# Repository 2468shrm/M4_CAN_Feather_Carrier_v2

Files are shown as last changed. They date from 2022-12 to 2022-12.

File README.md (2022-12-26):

# M4_CAN_Feather_Carrier_v2

## Board Layout
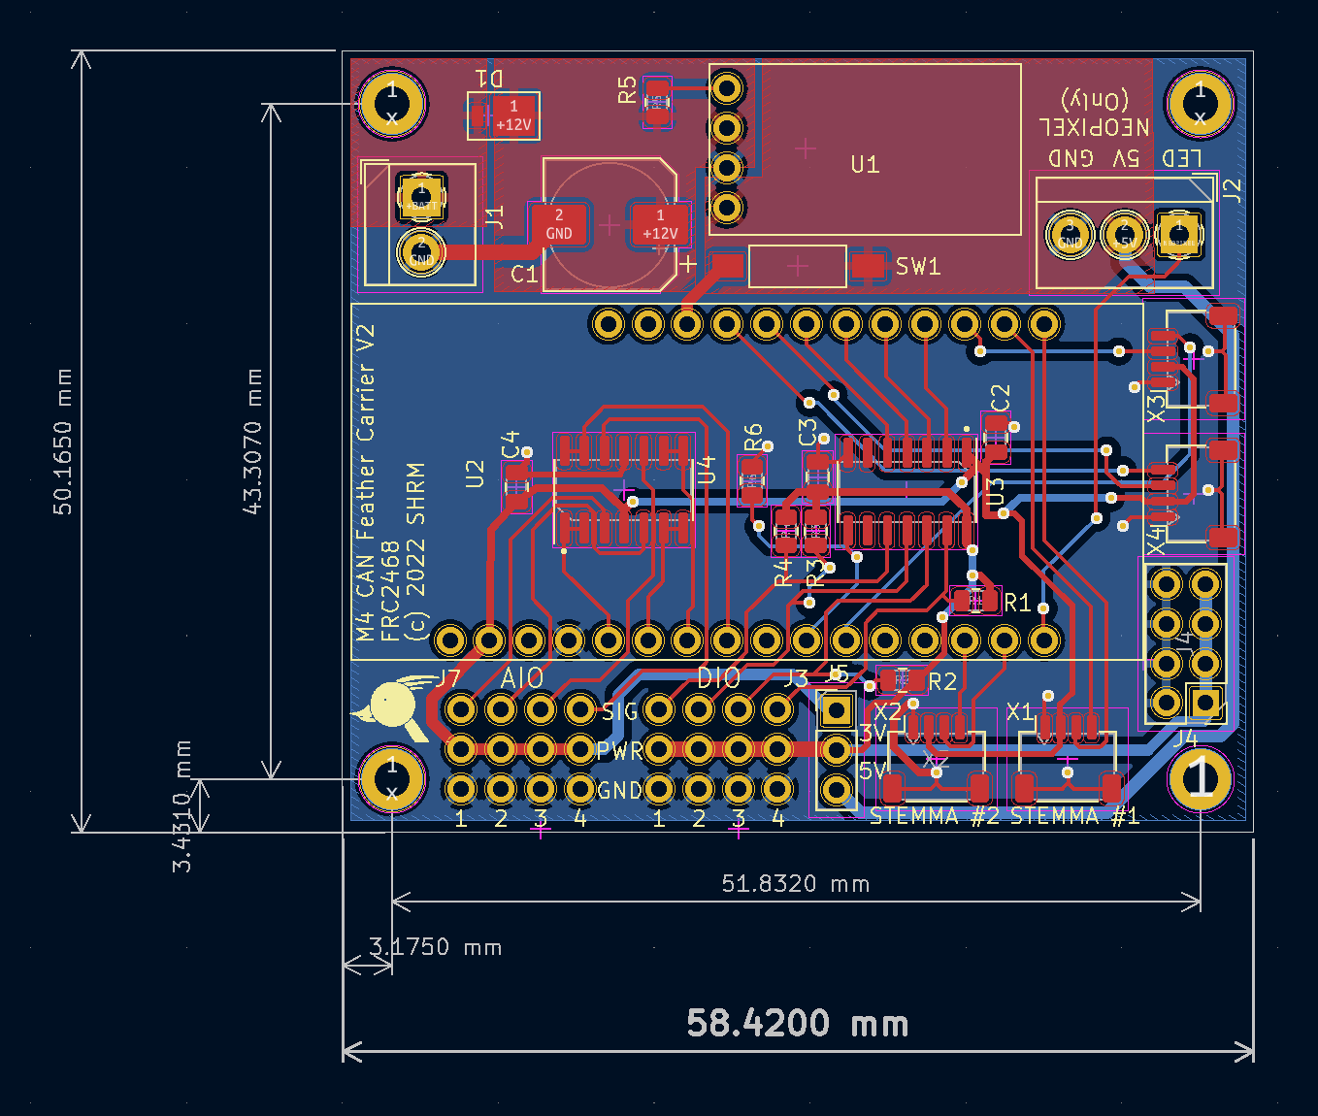
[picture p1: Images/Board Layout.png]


## Disclaimer
While I've tested a prior version of this board, this board is to be considered
alpha and subject to bugs and errors. Use at your own risk. However the Gerbers
are provided should you want to fabricate your own.

## Introduction
The carrier board is an adaptor to make using the Adafruit M4 CAN Express
Feather board more useful in FRC applications. This board was designed by mentors
of FRC2468/2687/2689. An initial version was done early in 2022, fabricated at JLCPCB
and tested to a limited degree. During the testing some weaknesses were identified and
initial design decisions questioned. Hence V2. Neither has received any actual FRC
use (it was not used by any of our teams during the 2022 competition season). However
a small number of these boards will be fabricated after the kickoff to the 2023 season.

This is the board as referenced in the [frc_can](https://github.com/2468shrm/frc_can)
project's CANCarrierBoard module (in
[can_carrier_board.py](https://github.com/2468shrm/frc_can/blob/main/can_carrier_board.py)).

## Board Description
The carrier board provides the following:
- Power interface (J1)
  - Power comes from a 12V supply through the provided 2-input screw terminal
  - The power supply contains a diode capacitor circuit to reduce the effects of FRC robot brownouts
- CAN interface
  - On the feather board
  - Note the feather board comes with termination included and active, so you must cut the termination trace jumper
- Analog I/O (AIO)
  - 4 analog inputs
  - Buffered with a unity gain opamp
  - Proded by 3-pin interface (similar to AIO on RoboRIO)
    - Pin 1: input analog signal
    - Pin 2: 3.3V supply
    - Pin 3: Ground
  - 3.3V input, max
- Digital I/O (DIO)
  - 4 digital inputs
  - Buffered with a level shifter
  - Selectable sensor voltage (VDD): 3.3V or 5V (all inputs share)
    - VDD selected by a jumper (J5)
    - 1-2 selects 3.3V
    - 2-3 selects 5V
  - Proded by 3-pin interface (similar to AIO on RoboRIO)
    - Pin 1: input analog signal
    - Pin 2: VDD supply
    - Pin 3: Ground
- Additional sensor power (J4)
	- A 2x4 header provided to provide additional VDD power to sensors
    - Intended for Adafruit beam break emitters or other multi-part sensors using an emitter and receiver pair where the receiver connects to DIO and emitter connects to the additional sensor power
- STEMMA QT/QWIIC (X1, X2, X3, X4)
  - 4 interfaces provided
- Neopixel (J2)
  - A Neopixel interface provided via a 3-input screw terminal
  - Intended to allow sensor to provide state of the sensor both over CAN and visually (i.e. sensor could be disconnected while still being useful)

## Power Interface
The initial version of this board was designed at the height of the pandemic's supply
chain shortage and so while I wanted to provide a 3A 5V supply (from 12V source) finding
the components was problematic at best. So I found a cheap, simple power supply module I
could acquire on Amazon. So I used it.

## DIO Level Shifter
The DIO interface has a level shifter between pins and MCU. The level shifter
A-side is 3.3V signaling due to the feather board's MCU requirements. The A-side
is expected to use internal pull ups if necessary. The B-side is VDD signaling
and is selected by the J5 jumper. The B-side pull ups are powered from the VDD
supply too.

The level shifter IC enable is driven by an MCU digital I/O and defaults to
off through a pull down resistor. Software must drive the OE signal high.

## Analog Buffer
A quad rail-to-rail opamp is used in unity-gain/follower configuration to buffer the
input signals to the MCU's ADCs. This is done so that sensors with large output
impedance may be connected to the ADC without significant loss in accuracy. Having
designed MCUs in the past, I'm quite aware of the effects on accuracy when using
potentiometers of 5K ohm. Most ADCs in MCUs have internal resistance and capacitacnce
that requires a low (80 ohm) source impedance to maintain spec'd accuracy.

## Updating the Programming
A switch (SW1, beside the power module) is provided to isolate the 5V generated by the
Weewooday module (U1) and the boost regulator on the Feather board. When programming a USB-C
cable is connected and the 5V is supplied on the feather board from this path. This would
lead to a contended supply. So, before programming change SW1 to open and plug in the board
to a host. Disconnect and change SW1 to closed to return to robot-supplied power.

# 3D Views of the Board
## Top
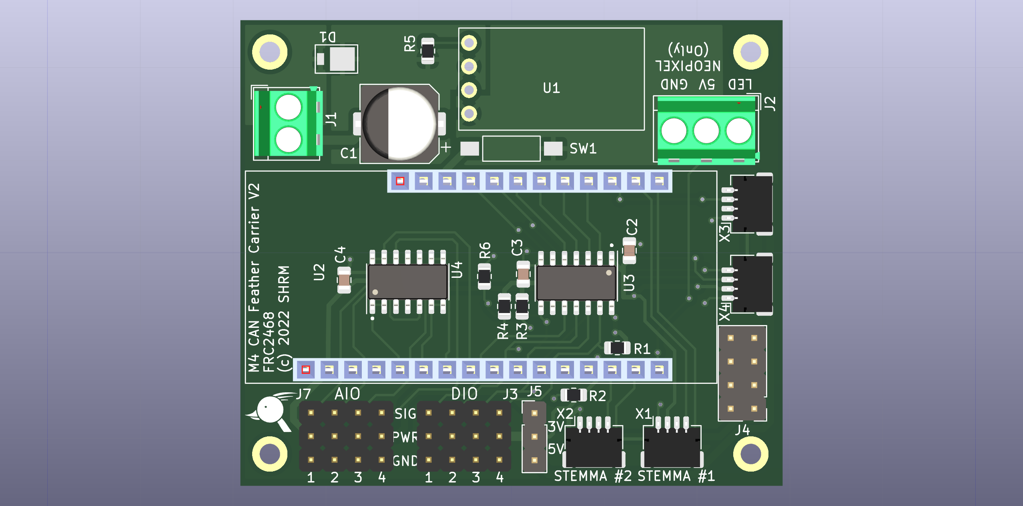
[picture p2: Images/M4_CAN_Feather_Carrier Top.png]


## Iso Front
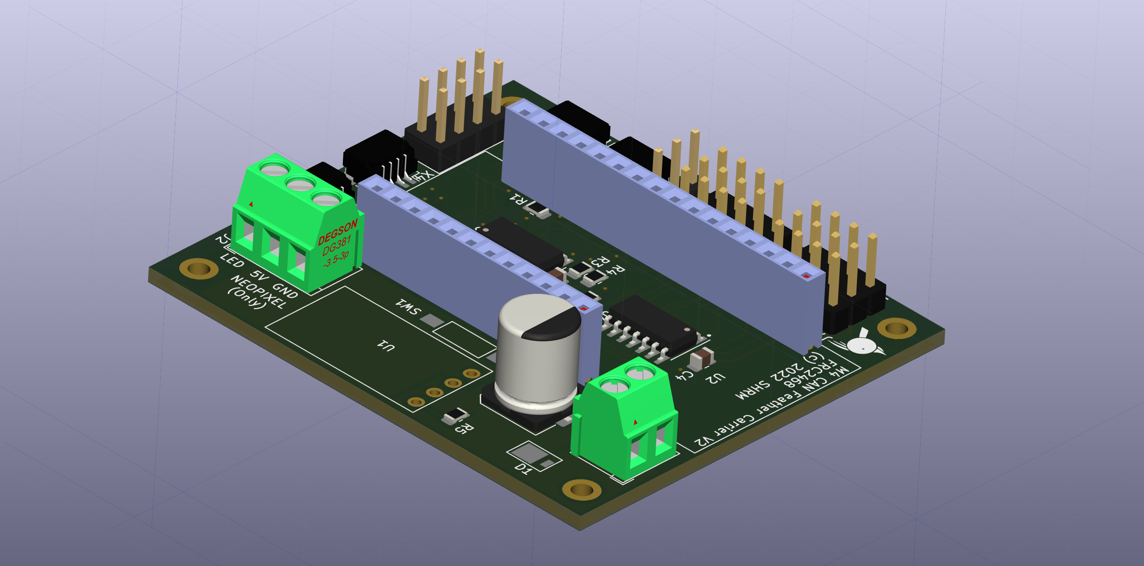
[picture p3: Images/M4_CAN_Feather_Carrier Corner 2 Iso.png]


## Iso Back
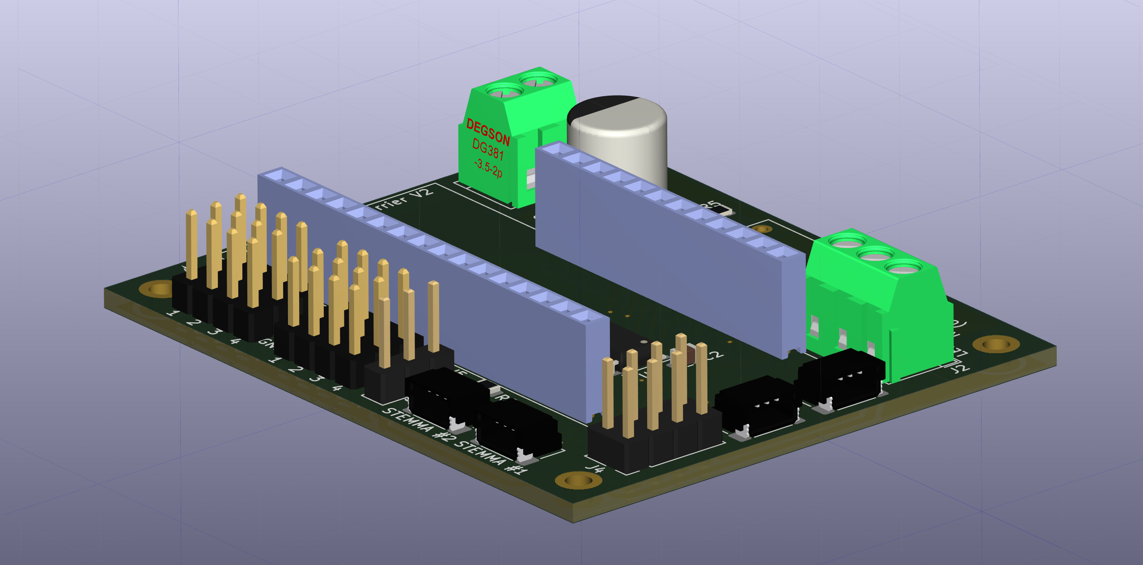
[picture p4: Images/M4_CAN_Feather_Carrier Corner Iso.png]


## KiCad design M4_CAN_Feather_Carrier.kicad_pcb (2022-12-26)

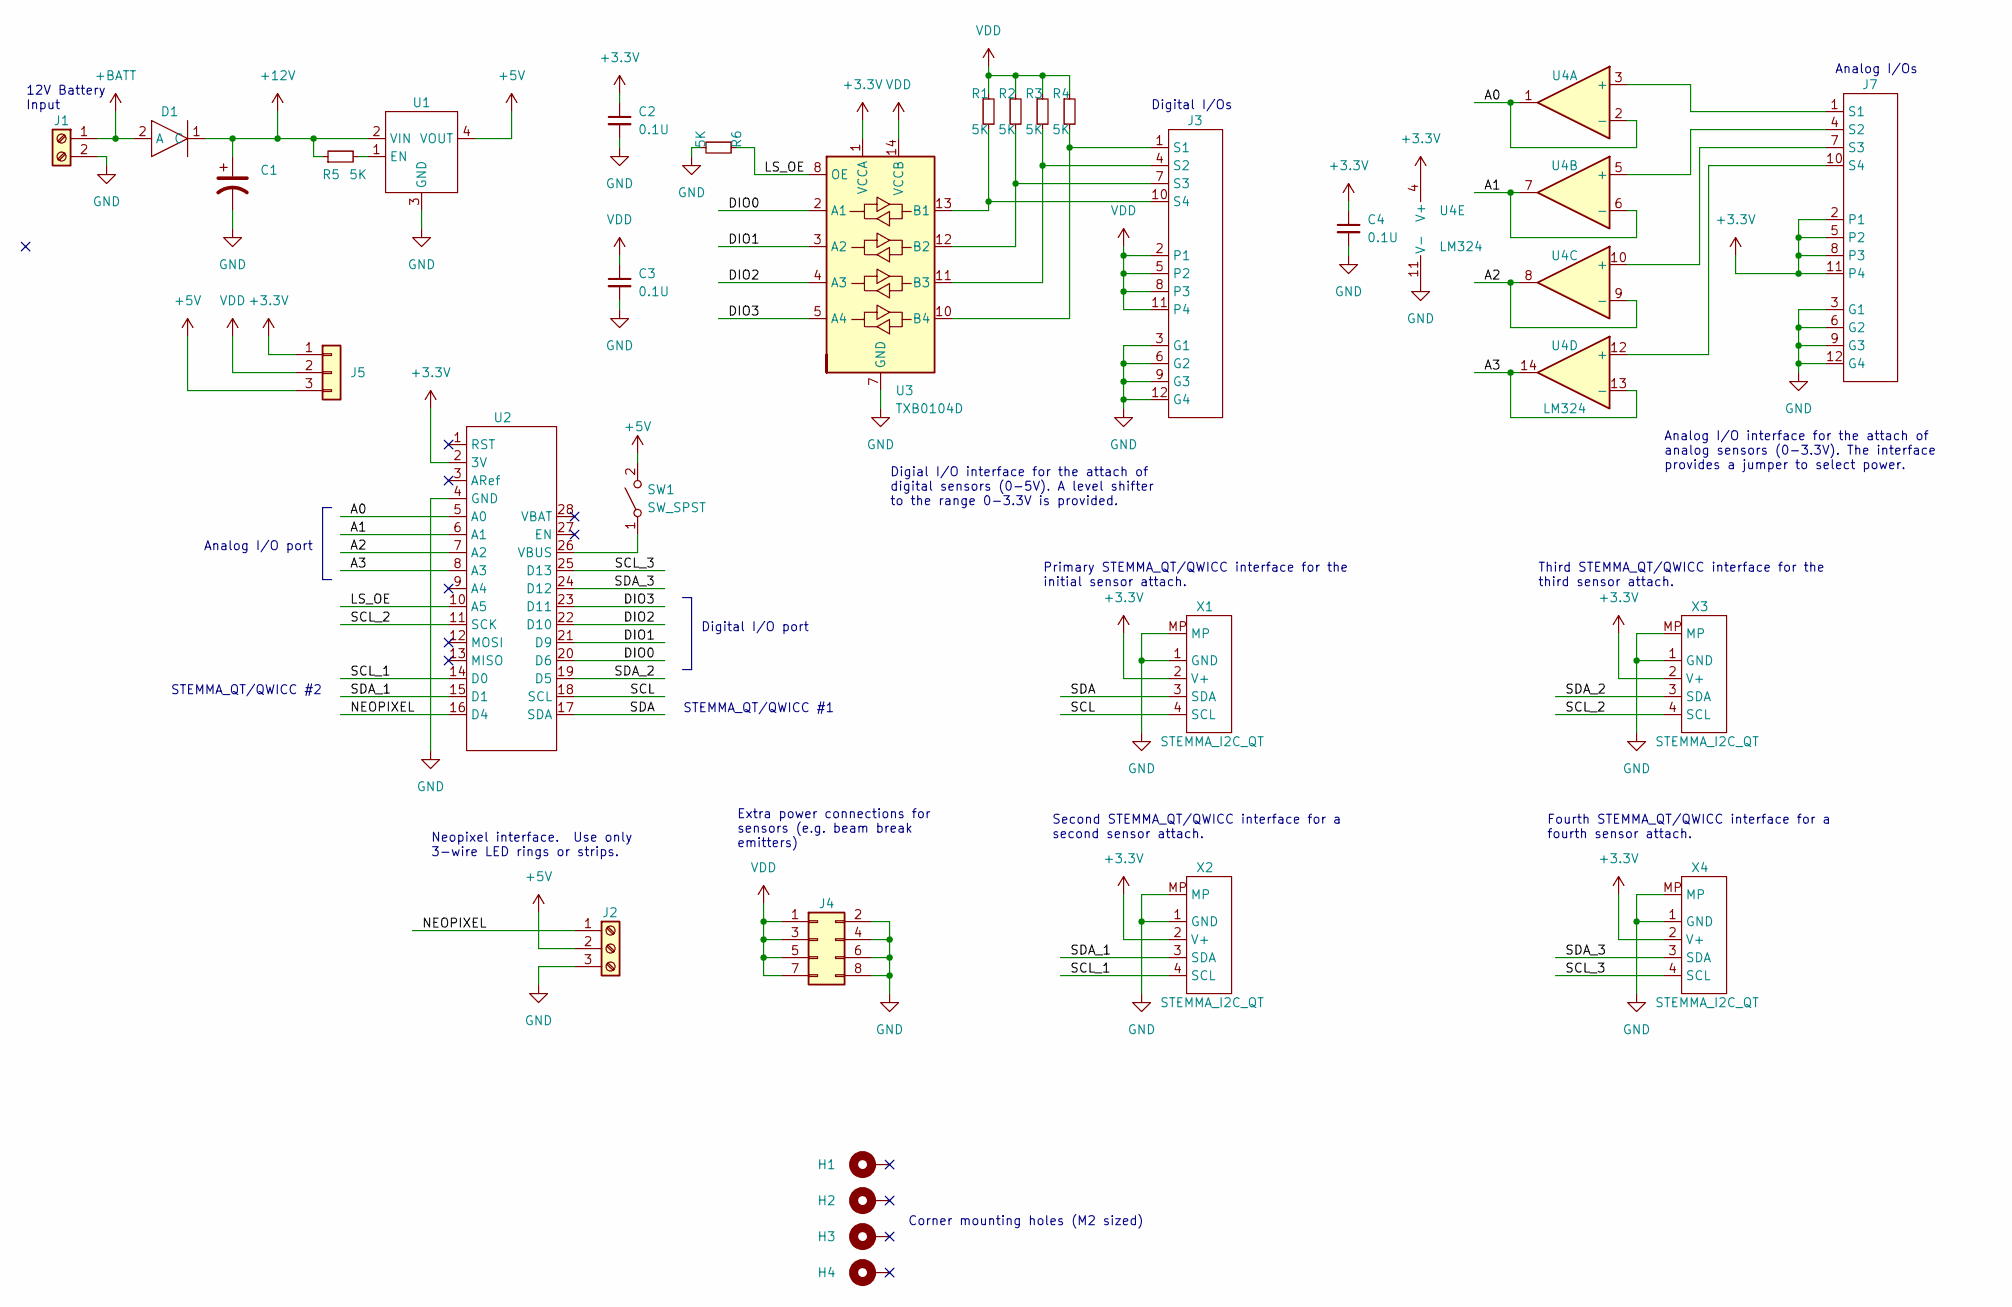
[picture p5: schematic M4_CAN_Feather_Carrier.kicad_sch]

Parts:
C1: 10u; CP_Elec_8x10
C2, C3, C4: 0.1U; C_0805_2012Metric
D1: UPR20e3; DO-216
H1, H2, H3, H4: MountingHole_Pad; MountingHole_2.2mm_M2_DIN965_Pad
J1: Screw_Terminal_01x02; TerminalBlock_4Ucon_1x02_P3.50mm_Horizontal
J2: Screw_Terminal_01x03; TerminalBlock_4Ucon_1x03_P3.50mm_Horizontal
J3, J7: conn_04_03; conn_04x03
J4: Conn_02x04_Odd_Even; PinHeader_2x04_P2.54mm_Vertical
J5: Conn_01x03; PinHeader_1x03_P2.54mm_Vertical
R1, R2, R3, R4, R5, R6: 5K; R_0805_2012Metric
SW1: SW_SPST; SPST-KJ01
U1: Weewooday-820
U2: Feather_M4_CAN_Express
U3: TXB0104D; SOIC-14_3.9x8.7mm_P1.27mm
U4: LM324; SOIC-14_3.9x8.7mm_P1.27mm
X1, X2, X3, X4: STEMMA_I2C_QT; JST_SH_SM04B-SRSS-TB_1x04-1MP_P1.00mm_Horizontal

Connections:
+3.3V: C2.1, C4.1, J5.1, J7.2 (P1), J7.5 (P2), J7.8 (P3), J7.11 (P4), U2.2 (3V), U3.1 (VCCA), U4.4 (V+), X1.2 (V+), X2.2 (V+), X3.2 (V+), X4.2 (V+)
+5V: J2.2, J5.3, SW1.2 (B), U1.4 (VOUT)
+12V: C1.1, D1.1 (C), R5.1, U1.2 (VIN)
+BATT: D1.2 (A), J1.1
/A0: U2.5 (A0), U4.1, U4.2 (-)
/A1: U2.6 (A1), U4.6 (-), U4.7
/A2: U2.7 (A2), U4.8, U4.9 (-)
/A3: U2.8 (A3), U4.13 (-), U4.14
/DIO0: U2.20 (D6), U3.2 (A1)
/DIO1: U2.21 (D9), U3.3 (A2)
/DIO2: U2.22 (D10), U3.4 (A3)
/DIO3: U2.23 (D11), U3.5 (A4)
/LS_OE: R6.1, U2.10 (A5), U3.8 (OE)
/NEOPIXEL: J2.1, U2.16 (D4)
/SCL: U2.18 (SCL), X1.4 (SCL)
/SCL_1: U2.14 (D0), X2.4 (SCL)
/SCL_2: U2.11 (SCK), X3.4 (SCL)
/SCL_3: U2.25 (D13), X4.4 (SCL)
/SDA: U2.17 (SDA), X1.3 (SDA)
/SDA_1: U2.15 (D1), X2.3 (SDA)
/SDA_2: U2.19 (D5), X3.3 (SDA)
/SDA_3: U2.24 (D12), X4.3 (SDA)
GND: C1.2, C2.2, C3.2, C4.2, J1.2, J2.3, J3.3 (G1), J3.6 (G2), J3.9 (G3), J3.12 (G4), J4.2, J4.4, J4.6, J4.8, J7.3 (G1), J7.6 (G2), J7.9 (G3), J7.12 (G4), R6.2, U1.3 (GND), U2.4 (GND), U3.7 (GND), U4.11 (V-), X1.1 (GND), X1.MP, X2.1 (GND), X2.MP, X3.1 (GND), X3.MP, X4.1 (GND), X4.MP
unnamed: J3.1 (S1), R4.2, U3.10 (B4)
unnamed: J3.4 (S2), R3.2, U3.11 (B3)
unnamed: J3.7 (S3), R2.2, U3.12 (B2)
unnamed: J3.10 (S4), R1.2, U3.13 (B1)
unnamed: J7.1 (S1), U4.3 (+)
unnamed: J7.4 (S2), U4.5 (+)
unnamed: J7.7 (S3), U4.10 (+)
unnamed: J7.10 (S4), U4.12 (+)
unnamed: R5.2, U1.1 (EN)
unnamed: SW1.1 (A), U2.26 (VBUS)
VDD: C3.1, J3.2 (P1), J3.5 (P2), J3.8 (P3), J3.11 (P4), J4.1, J4.3, J4.5, J4.7, J5.2, R1.1, R2.1, R3.1, R4.1, U3.14 (VCCB)

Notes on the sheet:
Corner mounting holes (M2 sized)
Digital I/Os
Analog I/Os
Third STEMMA_QT/QWICC interface for the third sensor attach.
Primary STEMMA_QT/QWICC interface for the initial sensor attach.
Extra power connections for sensors (e.g. beam break emitters)
Digial I/O interface for the attach of digital sensors (0-5V). A level shifter to the range 0-3.3V is provided.
Second STEMMA_QT/QWICC interface for a second sensor attach.
Digital I/O port
Analog I/O port
STEMMA_QT/QWICC #1
12V Battery Input
STEMMA_QT/QWICC #2
Analog I/O interface for the attach of analog sensors (0-3.3V). The interface provides a jumper to select power.
Neopixel interface. Use only 3-wire LED rings or strips.
Fourth STEMMA_QT/QWICC interface for a fourth sensor attach.

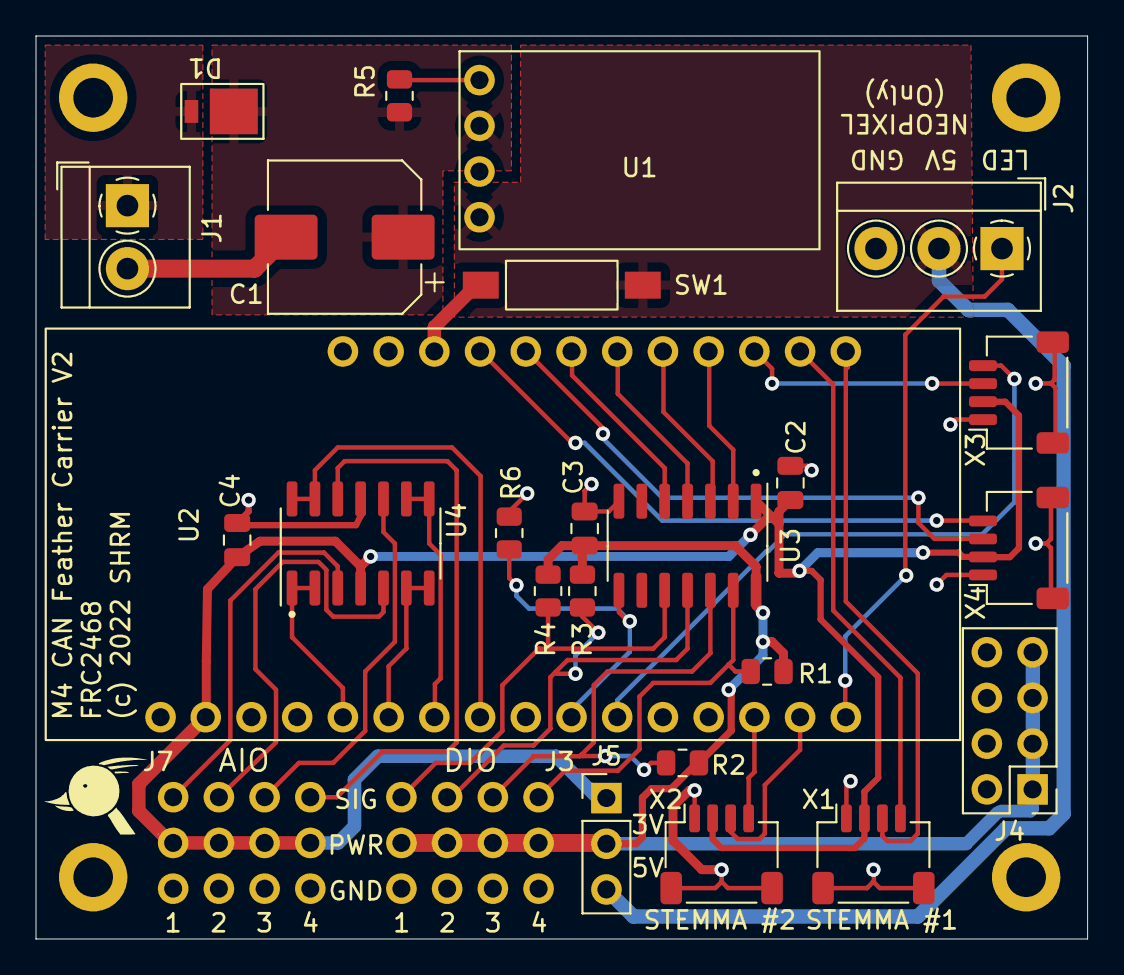
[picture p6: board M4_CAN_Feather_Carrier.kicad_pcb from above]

Board: 2 copper layers, 58.4 x 50.2 mm, 30 parts (0 on the bottom side), 34 nets.

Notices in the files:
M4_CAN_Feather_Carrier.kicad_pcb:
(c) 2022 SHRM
